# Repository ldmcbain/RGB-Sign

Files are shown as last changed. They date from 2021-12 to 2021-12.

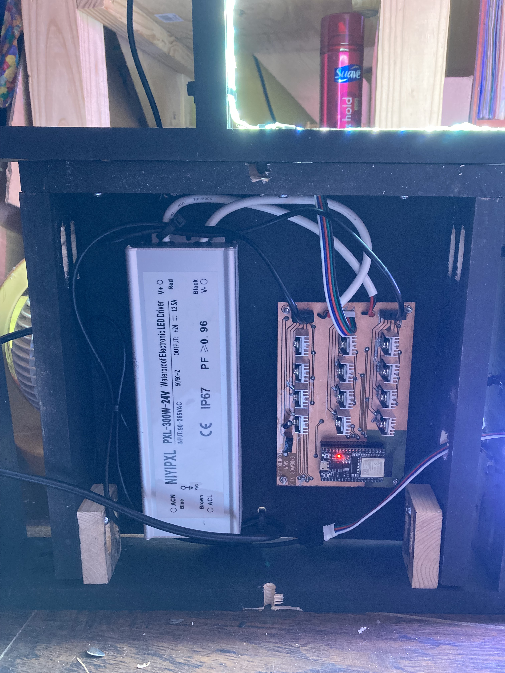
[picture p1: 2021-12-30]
Sign2.jpg

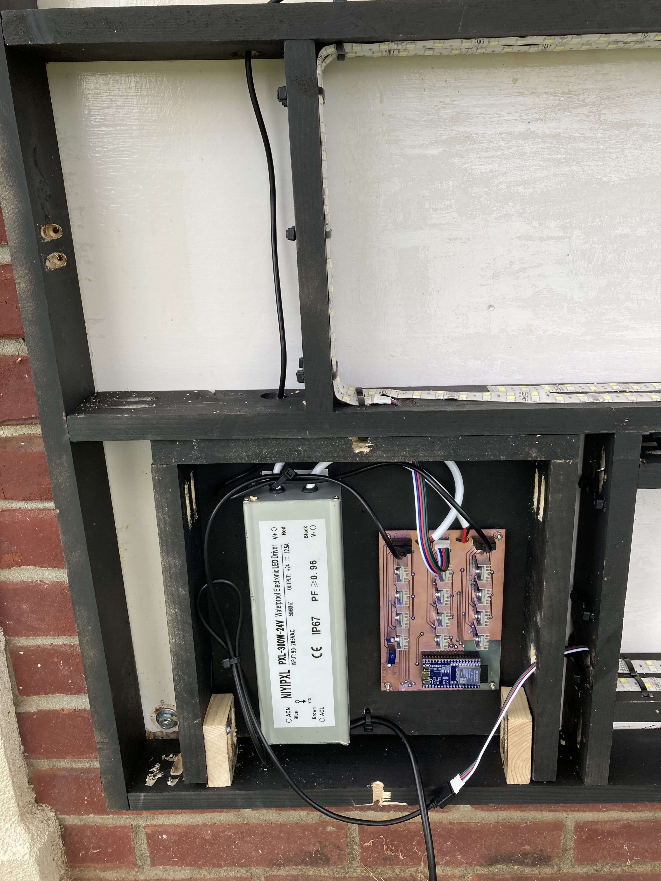
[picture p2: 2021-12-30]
Sign1.jpg

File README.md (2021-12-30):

# RGB Sign
 RGB Wifi Sign Controller using ESP32-DevkitC-32E

This is an RGB Sign I created for our church.  It is an Arduino based design using a custom PCB I created to conrol three separate RGB strings.  I created the PCB using a two-sided copper board and a laser burner, but someone could just as easily send it out for build.

The Arduino is setup to create a WIFI captive portal which is used to control the three strands. Update the wifi settings in the arduino code prior to use.

Note that the PCB uses the ESP32-DevkitC-32E layout.  Other ESP32 variations may have incorrect dimensions or pinouts.

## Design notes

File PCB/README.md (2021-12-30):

This PCB was created in KiCad v5.1.10

I generated the PCB using a standard 5W laser.  Here are my steps to do so if you are so inclined:

Like all things, follow these steps at your own risk.  This process involves toxic chemicals, soldering, etc and you must follow proper safety precautions if attempting.  If you are not comfortable with the equipment/process, don't do it.

**KiCad Design**
  Min Trace Width: 0.4mm
  Min Clearance: 0.25mm
  All Vias should be 2.5mm diameter and not placed under anything
  Use a ground flood plane on most surfaces (reduces required lasering)
  
**From within PCBNew**
  Plot out Top/Bottom Cu layers to PDF.  Utilize small drill holes, show cut edge on all layers
  
**Using GIMP**
1. Import PDF as high res (2400 dpi)
2. Auto Crop to content
3. Modify to fill in the outer edge so that it is all black (don't laser the edges)
4. Export as high res PNG

**Prepare the Board**
1. (optional) Sand the board lightly with 400 grit
2. Spray paint the board (both sides).  Make sure fully coated.  I used the cheap matte black spray at walmart.  Use two coats if needed.

**Lightburn Laser Control SW**
1. Import PNG into lightburn
2. Use Following settings for laser (this is what worked for me, modify as needed)
  a. 60% power
  b. speed: 3mm/s
  c. Bi-directional: Off
  d. Negative Image: On
  e. Overscanning: Off
  f. Line Interval: 0.1mm
  g. Passes: 1

**Burning and Post Clean up/Fabrication**
1. Position and Burn the Board (one side at a time..).  Note: you should be burning a Negative image on the board (areas in-between the copper).
2. Clean up board with scotch bright pad (and water).  Use a ultra fine tip marker to fix damaged areas if needed.
3. After both sides are burned, etch the board using ferric chloride solution.  This can be obtained from amazon.  USE GLOVES!!  There are several youtube videos showing how to do this if you are unfamiliar with the process.
4. Clean the board with water.  Inspect and re-etch if needed.
5. Use acetone or paint thinner to remove remaining paint from the board.
6. Clean board with alcohol (i use the 90% stuff at walmart)
7. Drill the holes.  I obtained very small drills from amazon for the purpose and used a drill press.  Use 0.8mm dia for vias.  They *should* be marked with small dots.  use the drill map to make sure you get all of them with the right size drills.
8. In some instances, I've found it helpful to pre-tin the board in certain locations.
9. Assemble the board.

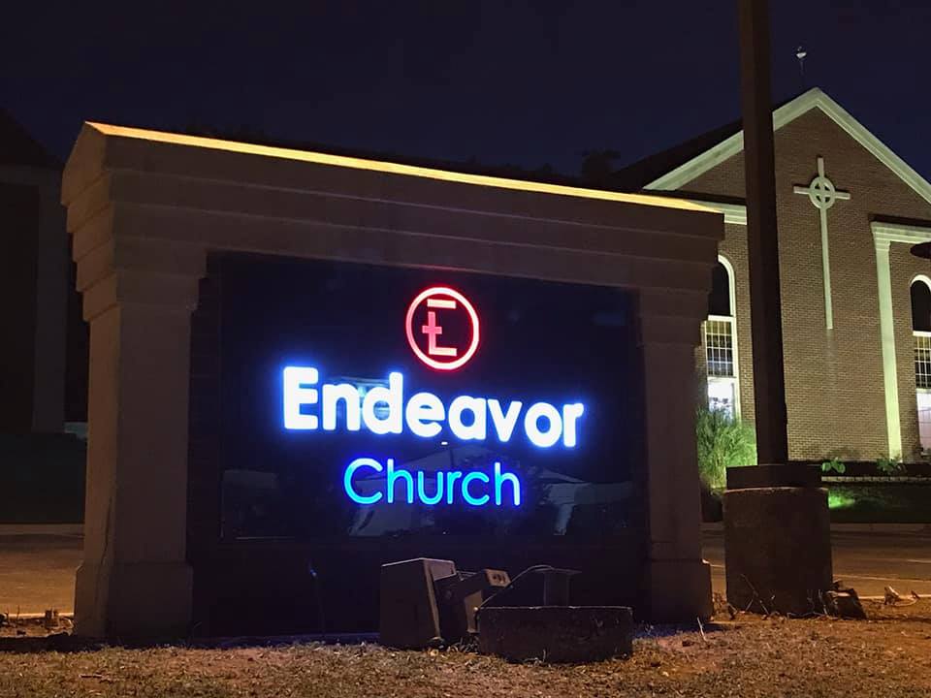
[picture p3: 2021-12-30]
Sign.jpg

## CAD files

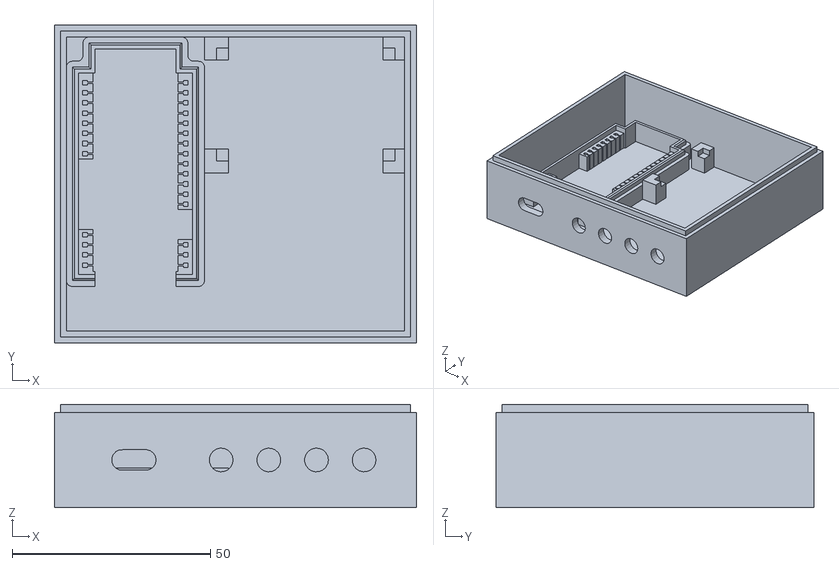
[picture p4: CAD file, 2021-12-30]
Sign/case/Bottom.stl
91.2 x 80.0 x 26.0

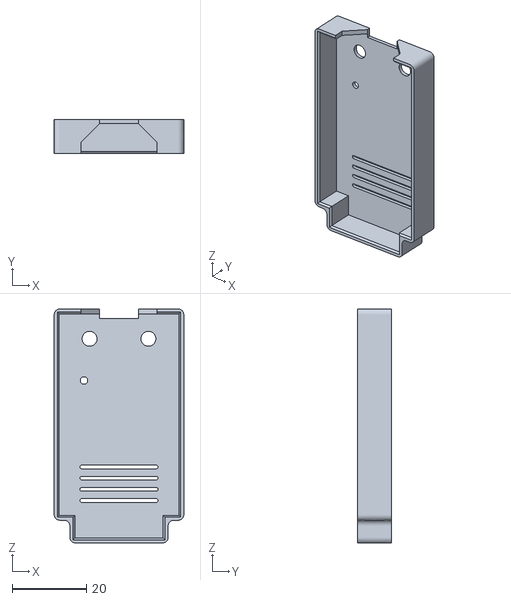
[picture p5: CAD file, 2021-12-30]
Sign/case/TapaESP32-DevKitC.stl
34.8 x 9.00 x 62.8

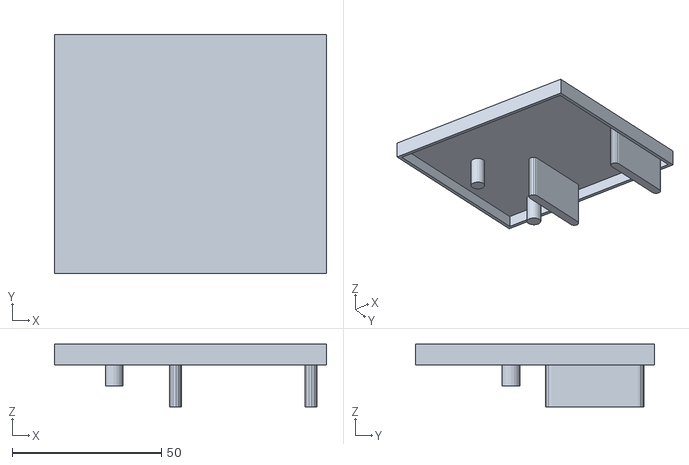
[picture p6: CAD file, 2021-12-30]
Sign/case/Top.stl
91.2 x 80.0 x 21.0

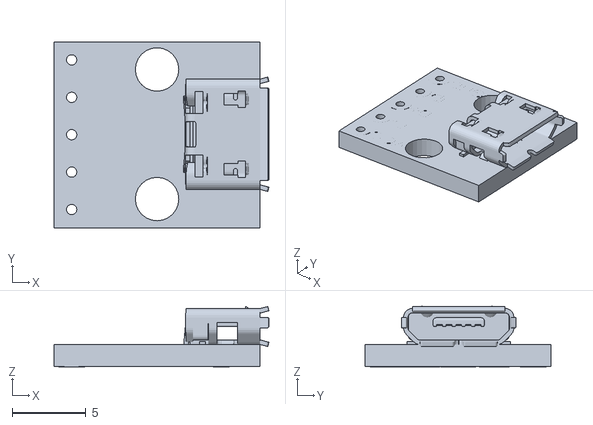
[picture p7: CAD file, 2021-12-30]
Sign/case/USBPinboard.stl
14.6 x 12.6 x 4.11

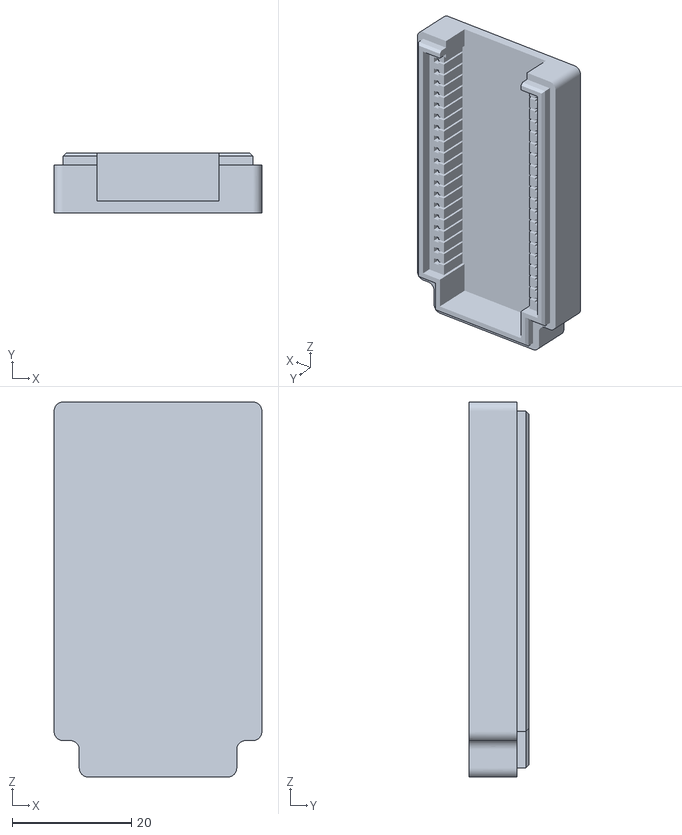
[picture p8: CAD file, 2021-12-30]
Sign/case/CajaESP32-DevKitC.stl
34.8 x 10.0 x 62.8

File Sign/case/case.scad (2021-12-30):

$fs=1;
$fa=3;

boxw=91.2;
boxl=80;
d=3;
boxh=29;

Bottom();
%Top();
pcbsupp();
%models();
BoxBot();
*BoxTop();

module BoxBot(){
  translate([-20.39,-37.3,-2])
difference(){
  cube([boxw,boxl,boxh-3]);
  translate([d,d,2])
  cube([boxw-2*d,boxl-2*d,50]);
  translate([0,0,boxh-5])
  difference(){
    translate([-5,-5,0])
    cube([boxw+10,boxl+10,3]);
    translate([1.5,1.5,-1])
    cube([boxw-3,boxl-3,3]);
  }
  translate([42,0,12])
  rotate([90,0,0])
  for(i=[0:3]){
    translate([12*i,0,0])
  cylinder(r=3,h=10,center=true);
  }
  
  //hole for usb pwr
  translate([17,0,12])
  rotate([90,0,0])
  hull(){
  cylinder(r=2.6,h=10,center=true);
    translate([6,0,0])
  cylinder(r=2.6,h=10,center=true);
  }
}   
}

module BoxTop(){
  translate([-20.39,42.7,boxh])
  rotate([180,0,0])
  union(){
    difference(){
      cube([boxw,boxl,7]);
      translate([d/2,d/2,2])
      cube([boxw-d,boxl-d,50]);
    }   
    
  translate([20,8,0])
  cylinder(r=3,h=14);
    
  translate([20,48,0])
  cylinder(r=3,h=14);
  
  for(i=[0,1]){
    hull(){
  for(j=[0,1]){
  translate([40.5+45.5*i,5.5+29*j,0])
  cylinder(r=2,h=21);
  }
  }}
}
}

module Bottom(){
rotate([90,0,0])
  difference(){
import("CajaESP32-DevKitC.stl",convexity=5);
    translate([-14.40,0,-0.1+2.54/2-2.54*4])
   cube([4,10,2.54*7]);
    translate([10.40,0,-0.1+2.54/2+2.54])
   cube([4,10,2.54*3]);
  }
}


module Top(){
rotate([90,0,0])
import("TapaESP32-DevKitC.stl",convexity=5);
}

module pcbsupp(){
  pcbw=45;
  pcbl=28.5;
  d=3;
  h=6;
translate([20.4-3,8.5-3,0])
difference(){
  translate([0,0,-2])
  cube([pcbw+2*d,pcbl+2*d,h+2+2]);
  translate([d*2,d*2,0])
  cube([pcbw-2*d,pcbl-2*d,12]);
  translate([d,d,h])
  cube([pcbw,pcbl,12]);
  translate([-d,d*2,0])
  cube([pcbw+d*4,pcbl-d*2,12]);
  translate([d*2,-d,0])
  cube([pcbw-d*2,pcbl+d*4,12]);
}
}

module models(){
translate([20.4,8.5,6])
cube([45,28.5,2]);
  
translate([7.5,-10,7])
rotate([0,0,-90])
import("usbpinboard.stl",convexity=5);
  
}

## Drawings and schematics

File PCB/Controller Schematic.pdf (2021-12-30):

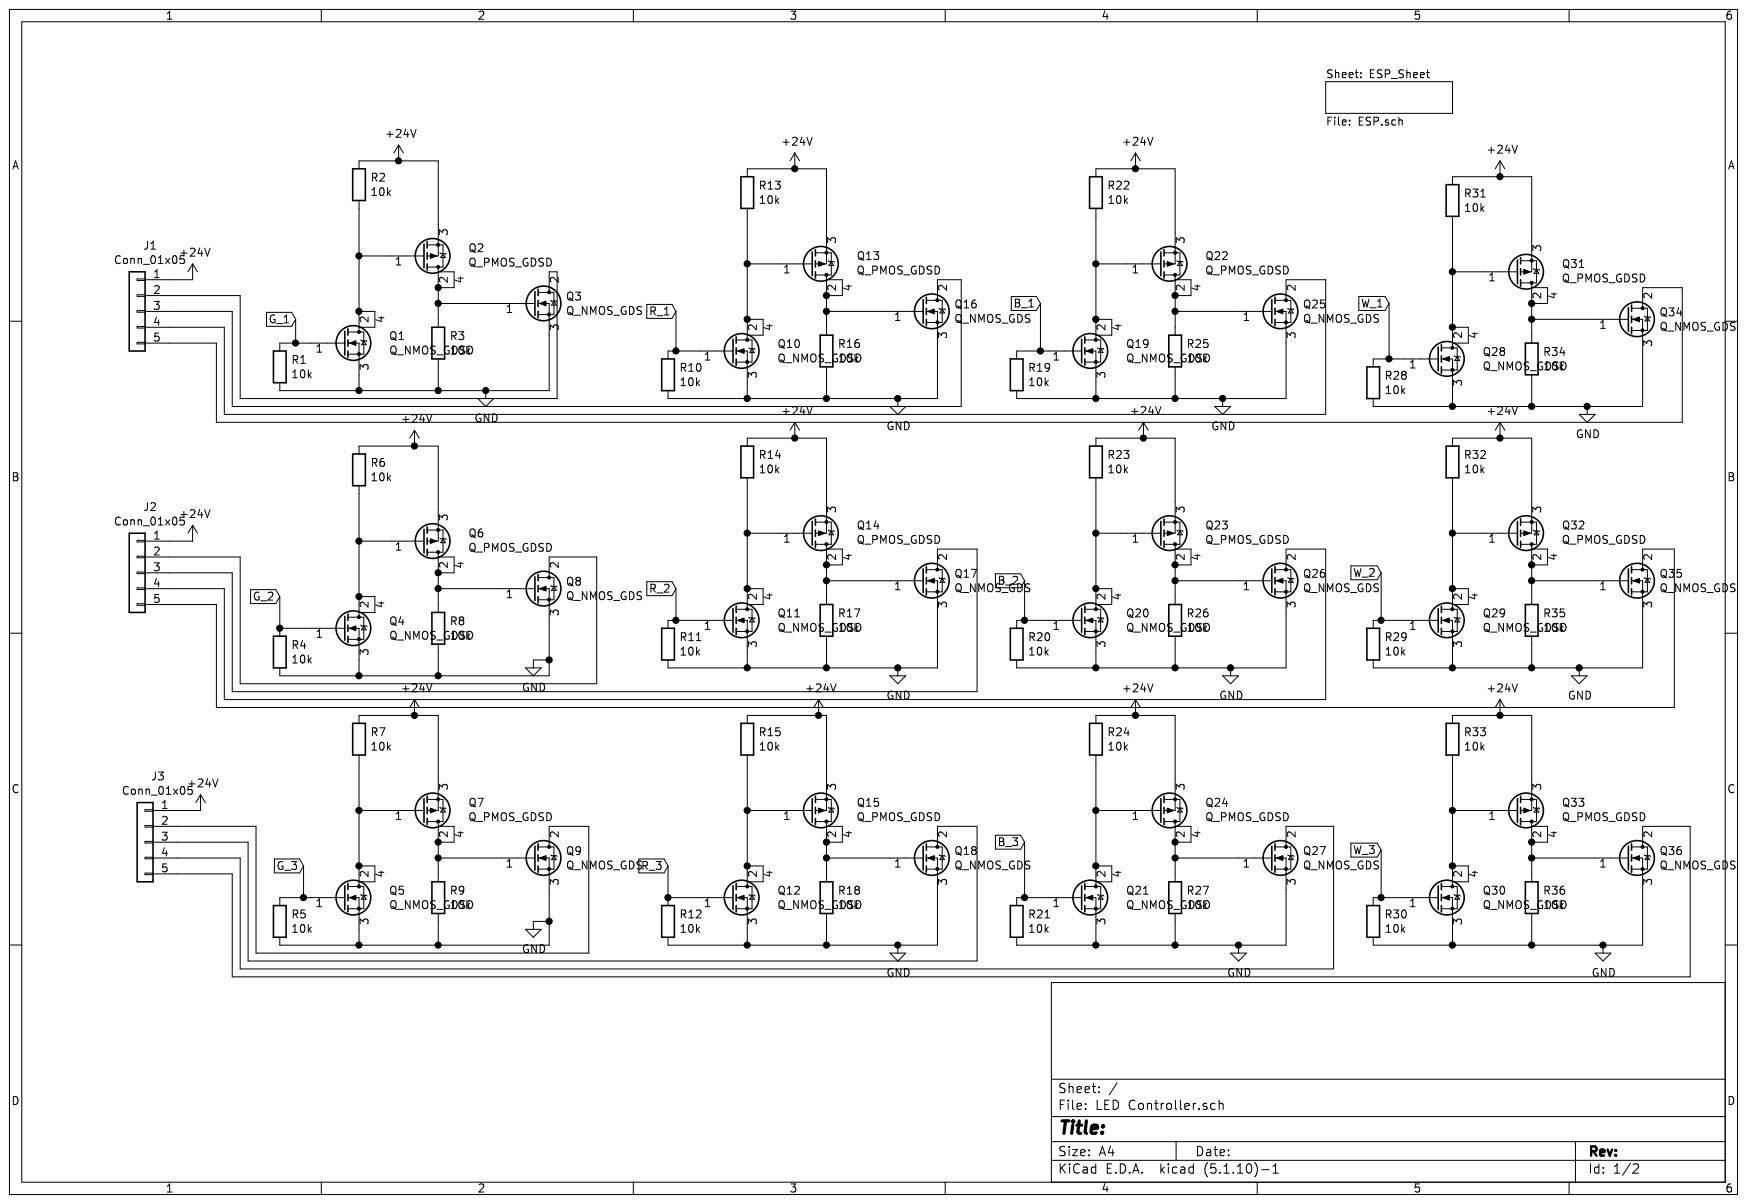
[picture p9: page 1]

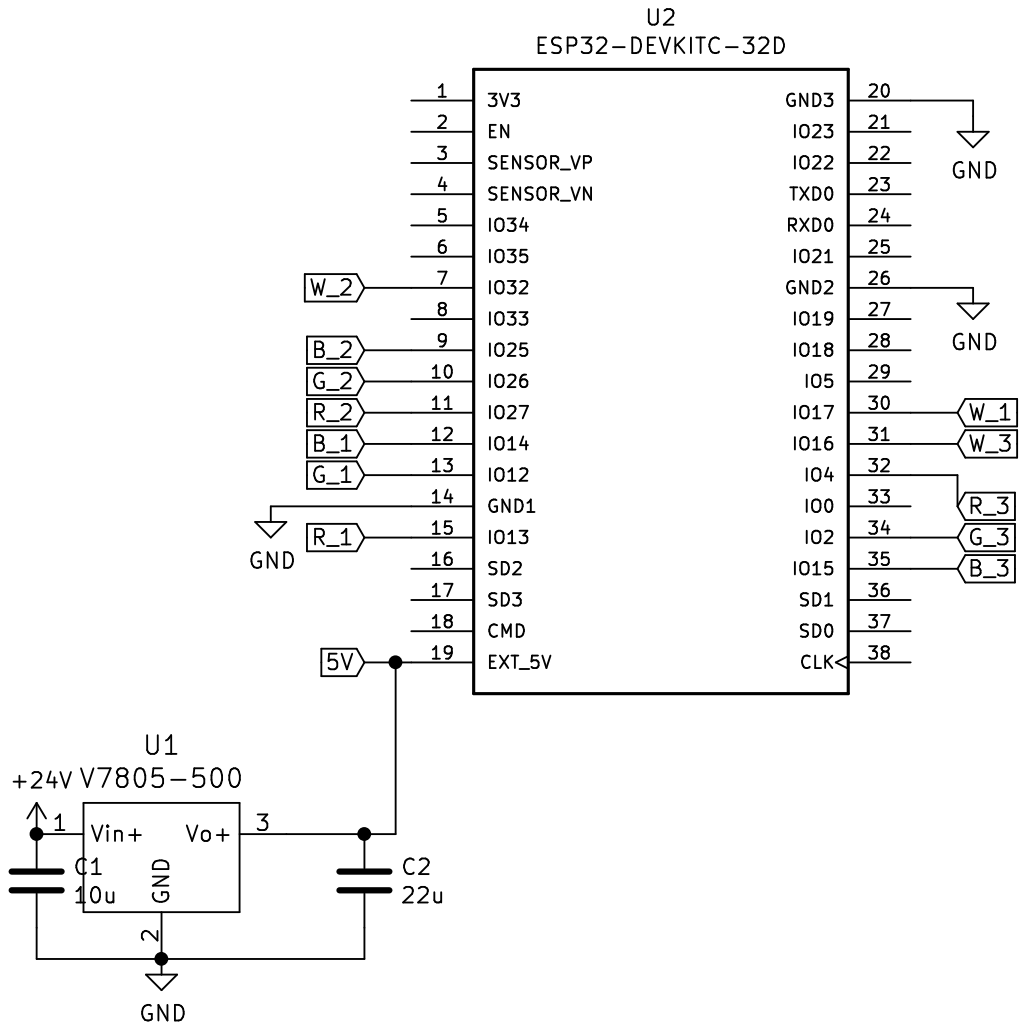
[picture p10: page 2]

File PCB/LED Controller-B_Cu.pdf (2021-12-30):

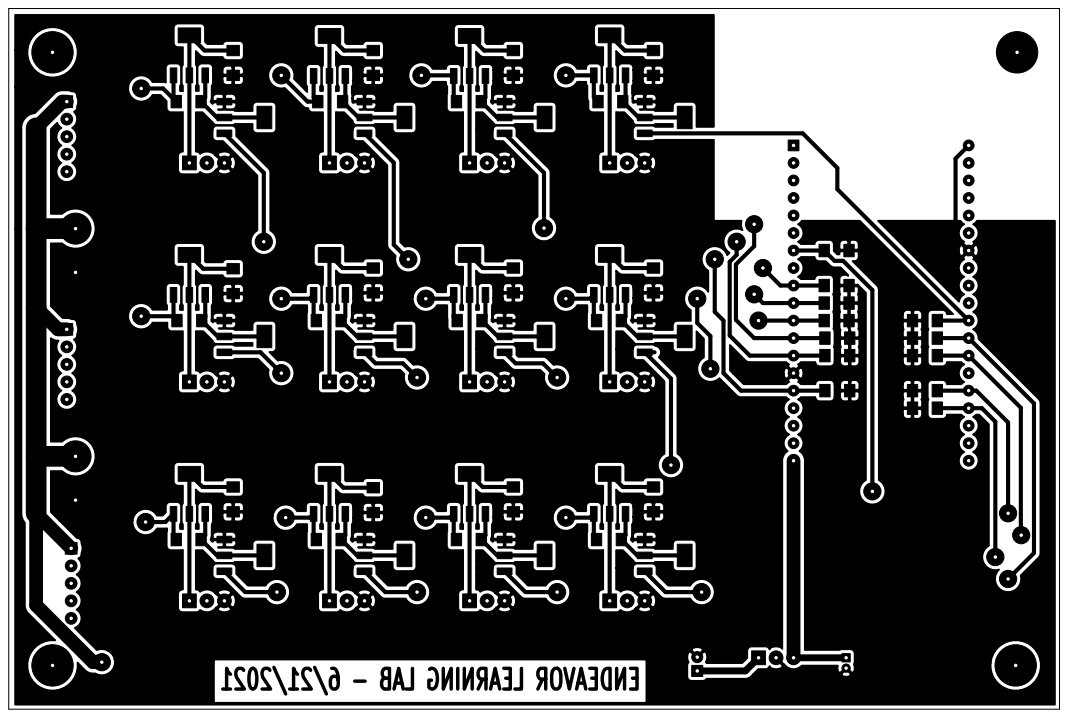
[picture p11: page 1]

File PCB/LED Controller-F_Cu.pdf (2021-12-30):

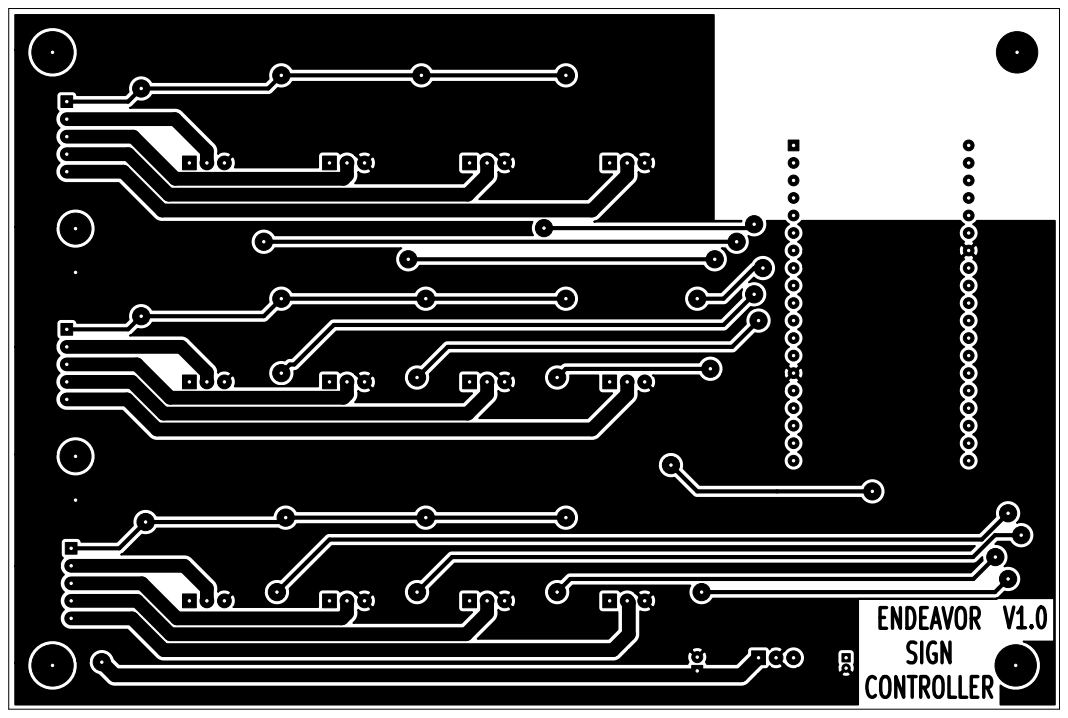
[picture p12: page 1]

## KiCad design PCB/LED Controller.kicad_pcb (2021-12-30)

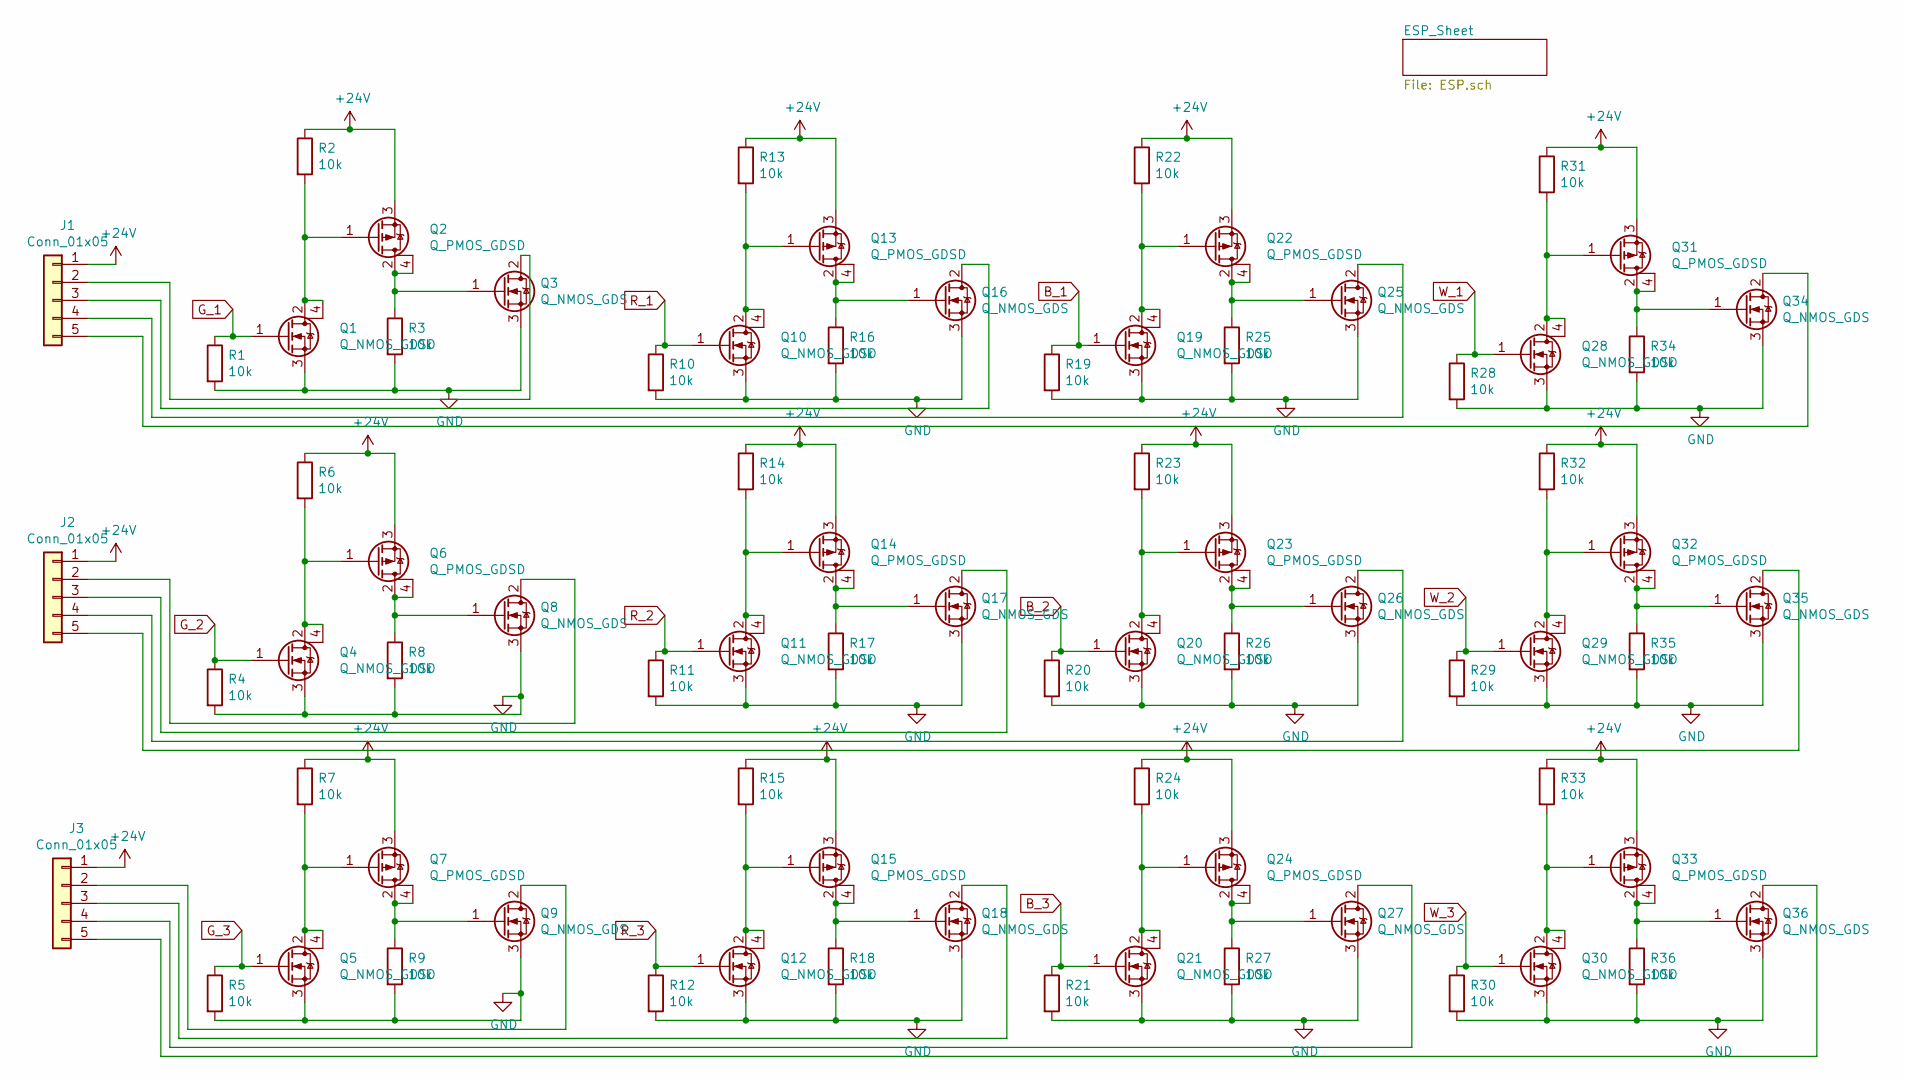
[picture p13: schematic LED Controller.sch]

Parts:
J1, J2, J3: Conn_01x05; PinHeader_1x05_P2.54mm_Vertical
Q1, Q4, Q5, Q10, Q11, Q12, Q19, Q20, Q21, Q28, Q29, Q30: Q_NMOS_GDSD; SOT-223-4
Q2, Q6, Q7, Q13, Q14, Q15, Q22, Q23, Q24, Q31, Q32, Q33: Q_PMOS_GDSD; SOT-223-4
Q3, Q8, Q9, Q16, Q17, Q18, Q25, Q26, Q27, Q34, Q35, Q36: Q_NMOS_GDS; TO-220-3_Heatsink
R1, R2, R3, R4, R5, R6, R7, R8, R9, R10, R11, R12, R13, R14, R15, R16, R17, R18, R19, R20, R21, R22, R23, R24, R25, R26, R27, R28, R29, R30, R31, R32, R33, R34, R35, R36: 10k; 1206

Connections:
+24V: J1.1, J2.1, J3.1, Q2.3 (S), Q6.3 (S), Q7.3 (S), Q13.3 (S), Q14.3 (S), Q15.3 (S), Q22.3 (S), Q23.3 (S), Q24.3 (S), Q31.3 (S), Q32.3 (S), Q33.3 (S), R2.1, R6.1, R7.1, R13.1, R14.1, R15.1, R22.1, R23.1, R24.1, R31.1, R32.1, R33.1; also elsewhere on the board
B_1: Q19.1 (G), R19.1; also elsewhere on the board
B_2: Q20.1 (G), R20.1; also elsewhere on the board
B_3: Q21.1 (G), R21.1; also elsewhere on the board
GND: Q1.3 (S), Q3.3 (S), Q4.3 (S), Q5.3 (S), Q8.3 (S), Q9.3 (S), Q10.3 (S), Q11.3 (S), Q12.3 (S), Q16.3 (S), Q17.3 (S), Q18.3 (S), Q19.3 (S), Q20.3 (S), Q21.3 (S), Q25.3 (S), Q26.3 (S), Q27.3 (S), Q28.3 (S), Q29.3 (S), Q30.3 (S), Q34.3 (S), Q35.3 (S), Q36.3 (S), R1.2, R3.2, R4.2, R5.2, R8.2, R9.2, R10.2, R11.2, R12.2, R16.2, R17.2, R18.2, R19.2, R20.2, R21.2, R25.2, R26.2, R27.2, R28.2, R29.2, R30.2, R34.2, R35.2, R36.2; also elsewhere on the board
G_1: Q1.1 (G), R1.1; also elsewhere on the board
G_2: Q4.1 (G), R4.1; also elsewhere on the board
G_3: Q5.1 (G), R5.1; also elsewhere on the board
unnamed: J1.2, Q3.2 (D)
unnamed: J1.3, Q16.2 (D)
unnamed: J1.4, Q25.2 (D)
unnamed: J1.5, Q34.2 (D)
unnamed: J2.2, Q8.2 (D)
unnamed: J2.3, Q17.2 (D)
unnamed: J2.4, Q26.2 (D)
unnamed: J2.5, Q35.2 (D)
unnamed: J3.2, Q9.2 (D)
unnamed: J3.3, Q18.2 (D)
unnamed: J3.4, Q27.2 (D)
unnamed: J3.5, Q36.2 (D)
unnamed: Q1.2 (D), Q1.4 (D), Q2.1 (G), R2.2
unnamed: Q2.2 (D), Q2.4 (D), Q3.1 (G), R3.1
unnamed: Q4.2 (D), Q4.4 (D), Q6.1 (G), R6.2
unnamed: Q5.2 (D), Q5.4 (D), Q7.1 (G), R7.2
unnamed: Q6.2 (D), Q6.4 (D), Q8.1 (G), R8.1
unnamed: Q7.2 (D), Q7.4 (D), Q9.1 (G), R9.1
unnamed: Q10.2 (D), Q10.4 (D), Q13.1 (G), R13.2
unnamed: Q11.2 (D), Q11.4 (D), Q14.1 (G), R14.2
unnamed: Q12.2 (D), Q12.4 (D), Q15.1 (G), R15.2
unnamed: Q13.2 (D), Q13.4 (D), Q16.1 (G), R16.1
unnamed: Q14.2 (D), Q14.4 (D), Q17.1 (G), R17.1
unnamed: Q15.2 (D), Q15.4 (D), Q18.1 (G), R18.1
unnamed: Q19.2 (D), Q19.4 (D), Q22.1 (G), R22.2
unnamed: Q20.2 (D), Q20.4 (D), Q23.1 (G), R23.2
unnamed: Q21.2 (D), Q21.4 (D), Q24.1 (G), R24.2
unnamed: Q22.2 (D), Q22.4 (D), Q25.1 (G), R25.1
unnamed: Q23.2 (D), Q23.4 (D), Q26.1 (G), R26.1
unnamed: Q24.2 (D), Q24.4 (D), Q27.1 (G), R27.1
unnamed: Q28.2 (D), Q28.4 (D), Q31.1 (G), R31.2
unnamed: Q29.2 (D), Q29.4 (D), Q32.1 (G), R32.2
unnamed: Q30.2 (D), Q30.4 (D), Q33.1 (G), R33.2
unnamed: Q31.2 (D), Q31.4 (D), Q34.1 (G), R34.1
unnamed: Q32.2 (D), Q32.4 (D), Q35.1 (G), R35.1
unnamed: Q33.2 (D), Q33.4 (D), Q36.1 (G), R36.1
R_1: Q10.1 (G), R10.1; also elsewhere on the board
R_2: Q11.1 (G), R11.1; also elsewhere on the board
R_3: Q12.1 (G), R12.1; also elsewhere on the board
W_1: Q28.1 (G), R28.1; also elsewhere on the board
W_2: Q29.1 (G), R29.1; also elsewhere on the board
W_3: Q30.1 (G), R30.1; also elsewhere on the board

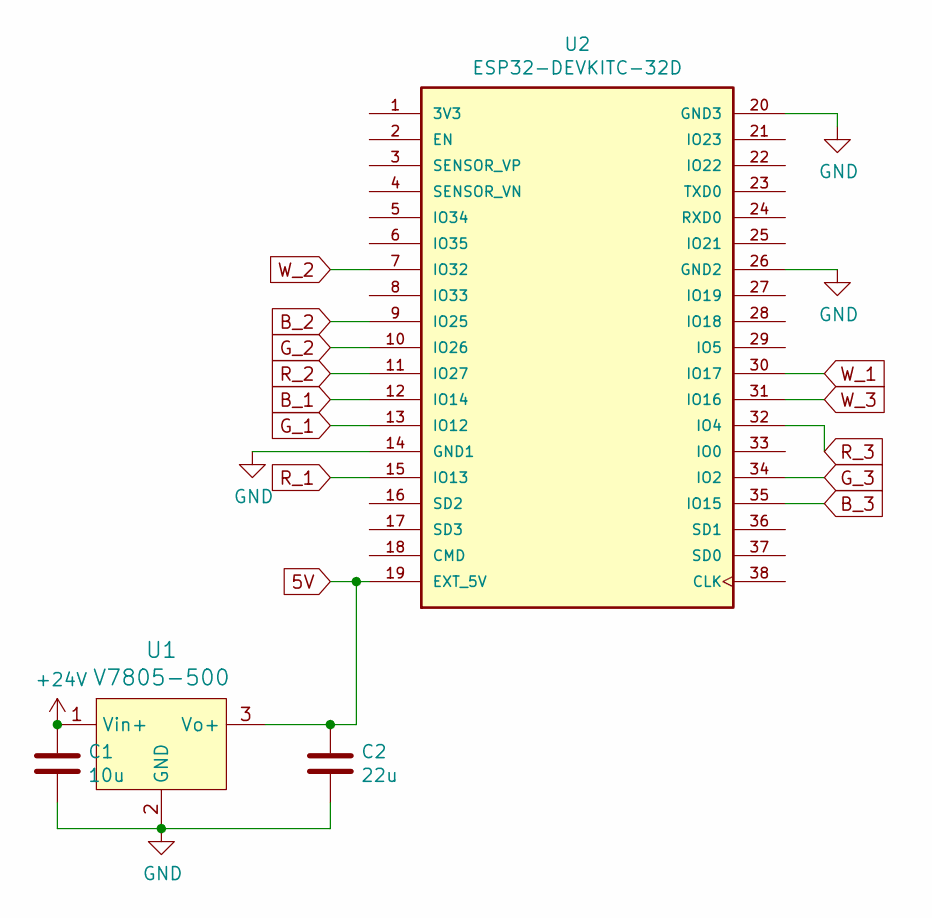
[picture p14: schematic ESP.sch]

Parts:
C1: 10u; CP_Radial_D5.0mm_P2.00mm
C2: 22u; CP_Radial_D4.0mm_P1.50mm
U1: V7805-500; 3-SIP_Module_V7805-500; MPN V7805-500; Digi-Key_PN 102-1709-ND
U2: ESP32-DEVKITC-32D; MODULE_ESP32-DEVKITC-32D; PARTREV 4

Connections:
5V: C2.1, U1.3 (Vo+), U2.19 (EXT_5V)
+24V: C1.1, U1.1 (Vin+); also elsewhere on the board
B_1: U2.12 (IO14); also elsewhere on the board
B_2: U2.9 (IO25); also elsewhere on the board
B_3: U2.35 (IO15); also elsewhere on the board
GND: C1.2, C2.2, U1.2 (GND), U2.14 (GND1), U2.20 (GND3), U2.26 (GND2); also elsewhere on the board
G_1: U2.13 (IO12); also elsewhere on the board
G_2: U2.10 (IO26); also elsewhere on the board
G_3: U2.34 (IO2); also elsewhere on the board
R_1: U2.15 (IO13); also elsewhere on the board
R_2: U2.11 (IO27); also elsewhere on the board
R_3: U2.32 (IO4); also elsewhere on the board
W_1: U2.30 (IO17); also elsewhere on the board
W_2: U2.7 (IO32); also elsewhere on the board
W_3: U2.31 (IO16); also elsewhere on the board

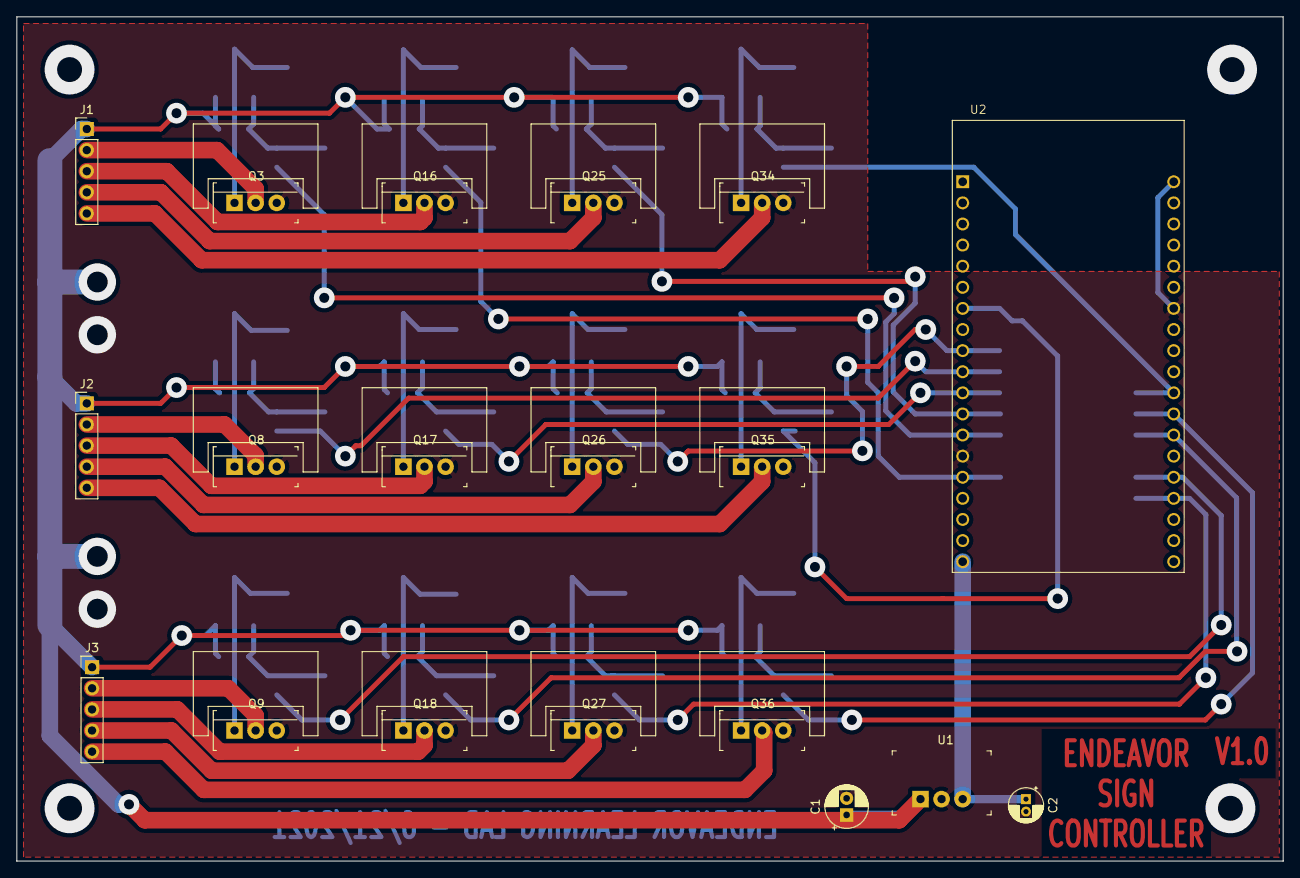
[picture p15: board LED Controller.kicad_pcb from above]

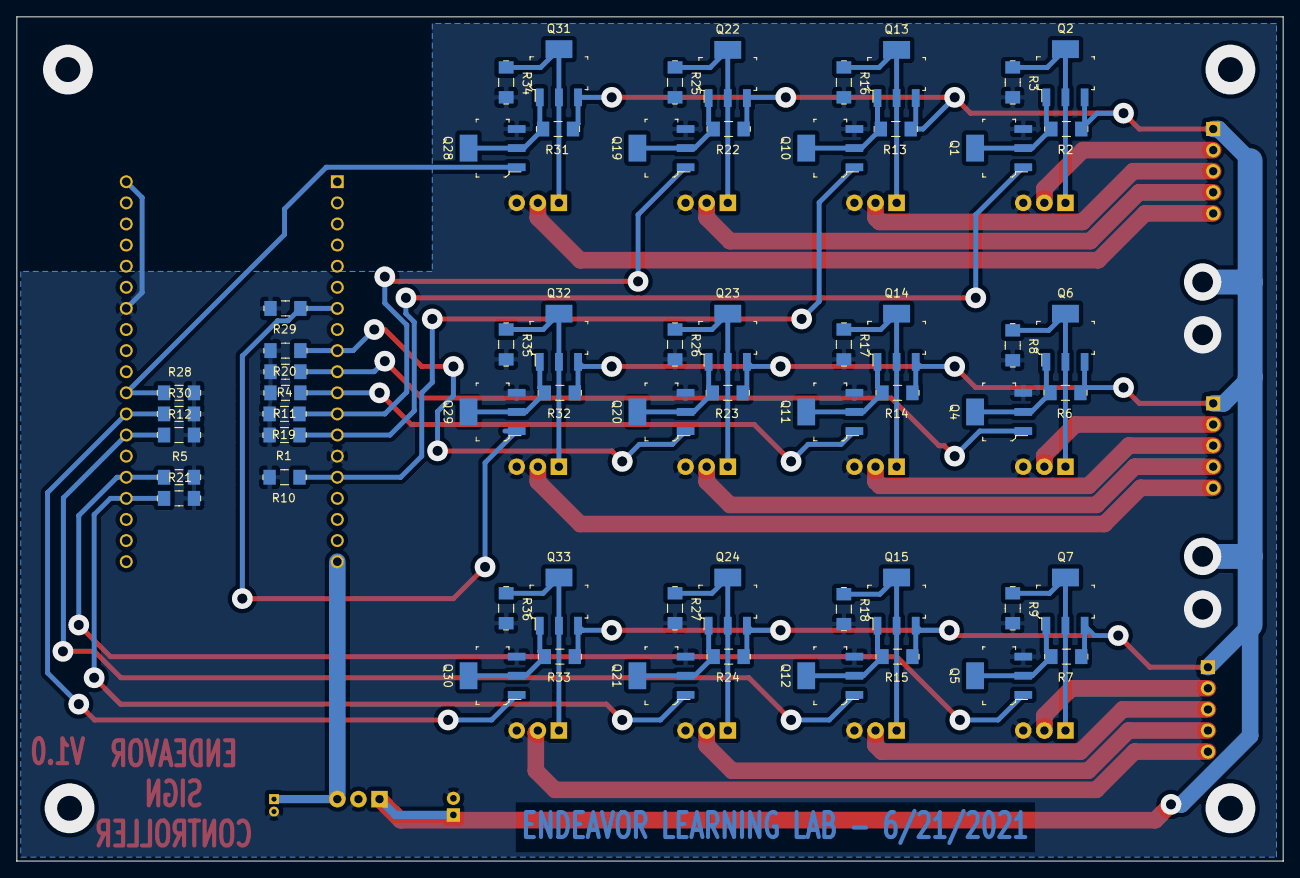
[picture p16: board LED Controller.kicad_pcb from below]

Board: 2 copper layers, 152.4 x 101.6 mm, 79 parts (60 on the bottom side), 51 nets.

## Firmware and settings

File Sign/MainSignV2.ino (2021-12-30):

/*
 * ENDEAVOR LED SIGN CONTROL
 * This project was created by Endeavor Labs (a mission of Endeavor Church) to create
 * an LED controller for the main front sign.  
 * 
 * The system is to be designed to use a ESP32 Dev board to control 3 separate
 * RGBW 5050 LED strips.  The LEDs will be driven via NMOS FETs on the attached 
 * PCB.
 * 
 * This software is designed to create a permanent Access Point with a captive portal
 * to a webpage which will control the three strings using the jscolor color picker 
 * (jscolor.js stored in SPIFFS). The device will then present the user with the
 * ability to save the settings to EEPROM so that the unit will restore settings
 * upon reboot (which will occurr nightly).
 * 
 * This is version 2 which added the white LEDs and also is being used with
 * the incorporated PCB attached to the project.
 * 
 * Board - ESP32 Dev Module
 * Upload Speed - 115200
 * CPU Freq - 240MHz
 * Flash Freq 40MHz
 * Mode - QIO
 * Flash size - 4MB (32Mb)
 * Partition - Default 4MB wigh SPIFFS (1.2MB APP/1.5MB SPIFFS)
 */

#include <Arduino.h>
#include <WebServer.h>
#include <DNSServer.h>
#include "./server_html.h"
#include "./myeeprom.h"
#include <SPIFFS.h>

#define FILESYSTEM SPIFFS

// Replace with your network credentials
const char* ssid     = "XXXXXXXX";
const char* password = "XXXXXXXX";

// Set web server port number to 80
WebServer server(80);
const byte DNS_PORT = 53;
IPAddress apIP(192, 168, 1, 1);
DNSServer dnsServer;

// Red, green, and blue pins for PWM control
const int redPin[MAX_leds] = {13,27,4};     // 13 corresponds to GPIO13
const int greenPin[MAX_leds] = {12,26,2};   // 12 corresponds to GPIO12
const int bluePin[MAX_leds] = {14,25,15};    // 14 corresponds to GPIO14
const int whitePin[MAX_leds] = {17,32,16};    // 14 corresponds to GPIO14

// Setting PWM frequency, channels and bit resolution
//resolution set down to 300 to improve resolution in low/high settings.
const int freq = 300;
const int redChannel[MAX_leds] = {0,1,2};
const int greenChannel[MAX_leds] = {3,4,5};
const int blueChannel[MAX_leds] = {6,7,8};
const int whiteChannel[MAX_leds] = {9,10,11};
// Bit resolution 2^8 = 256
const int resolution = 8;

int redInt[3] = {0,0,0};
int blueInt[3] = {0,0,0};
int greenInt[3] = {0,0,0};
int whiteInt[3] = {0,0,0};

void handleRoot()
{
  buildWebsite();
  server.send(200, "text/html", webSite);
}

void handleLED1()
{
  handleLED(0,server.arg("r"),server.arg("g"),server.arg("b"));
}

void handleLED2()
{
  handleLED(1,server.arg("r"),server.arg("g"),server.arg("b"));
}

void handleLED3()
{
  handleLED(2,server.arg("r"),server.arg("g"),server.arg("b"));
}

void handleWHITE1()
{
  handleWHITE(0,server.arg("w"));
}

void handleWHITE2()
{
  handleWHITE(1,server.arg("w"));
}

void handleWHITE3()
{
  handleWHITE(2,server.arg("w"));
}

void handleSAVE()
{
  Serial.println("Saving Settings");
  int i;
  for(i=0;i<MAX_leds;i++)
  {
    Serial.printf("R%i:%s G%i:%s B%i:%s W%i:%s ",i,redString[i].c_str(),i,greenString[i].c_str(),i,blueString[i].c_str(),i,whiteString[i].c_str());
  }
  Serial.println("");
  saveSettings(redString[0],greenString[0],blueString[0],whiteString[0],
               redString[1],greenString[1],blueString[1],whiteString[1],
               redString[2],greenString[2],blueString[2],whiteString[2]);
}

void handleRESTORE()
{
  getStoredSettings();
  redString[0]=String(romSettings.RD1);
  greenString[0]=String(romSettings.GR1);
  blueString[0]=String(romSettings.BL1);
  whiteString[0]=String(romSettings.WH1);
  redString[1]=String(romSettings.RD2);
  greenString[1]=String(romSettings.GR2);
  blueString[1]=String(romSettings.BL2);
  whiteString[1]=String(romSettings.WH2);
  redString[2]=String(romSettings.RD3);
  greenString[2]=String(romSettings.GR3);
  blueString[2]=String(romSettings.BL3);
  whiteString[2]=String(romSettings.WH3);

  
  Serial.println("Restore String Settings");
  int i;
  for(i=0;i<MAX_leds;i++)
  {
    Serial.printf("R%i:%s G%i:%s B%i:%s W%i:%s ",i,redString[i].c_str(),i,greenString[i].c_str(),i,blueString[i].c_str(),i,whiteString[i].c_str());
  }
  Serial.println("");
  
  for(i=0;i<MAX_leds;i++)
  {
    handleLED(i,redString[i],greenString[i],blueString[i]);
    handleWHITE(i,whiteString[i]);
  }
}

void handleLED(int LED, String r, String g, String b)
{  
  redString[LED] = r;
  greenString[LED] = g;
  blueString[LED] = b;
  
  ledcWrite(redChannel[LED], r.toInt());
  ledcWrite(greenChannel[LED], g.toInt());
  ledcWrite(blueChannel[LED], b.toInt());
  
  Serial.print("LED");
  Serial.print(LED);
  Serial.print(" Set to: RED:");
  Serial.print(r);
  Serial.print(" GREEN:");
  Serial.print(g);
  Serial.print(" BLUE:");
  Serial.println(b);
}

void handleWHITE(int LED, String w)
{
  whiteString[LED] = w;
  ledcWrite(whiteChannel[LED], w.toInt());
  
  Serial.print("LED");
  Serial.print(LED);
  Serial.print(" Set to: WHITE:");
  Serial.println(w);
}

void setup() {
  Serial.begin(115200);
  int i;
  for(i=0;i<MAX_leds;i++)
  {
    // configure LED PWM functionalitites
    ledcSetup(redChannel[i], freq, resolution);
    ledcSetup(greenChannel[i], freq, resolution);
    ledcSetup(blueChannel[i], freq, resolution);
    ledcSetup(whiteChannel[i], freq, resolution);
    
    // attach the channel to the GPIO to be controlled
    ledcAttachPin(redPin[i], redChannel[i]);
    ledcAttachPin(greenPin[i], greenChannel[i]);
    ledcAttachPin(bluePin[i], blueChannel[i]);
    ledcAttachPin(whitePin[i], whiteChannel[i]);
  }

  // Initialize SPIFFS
  if(!FILESYSTEM.begin(true)){
    Serial.println("An Error has occurred while mounting SPIFFS");
    return;
  }

  //restore settings from EEPROM
  handleRESTORE();
  
  // Connect to Wi-Fi network with SSID and password
  Serial.print("Starting AP ");
  Serial.println(ssid);

  WiFi.mode(WIFI_AP);
  Serial.println(WiFi.softAP(ssid, password) ? "soft-AP setup": "Failed to connect");
  delay(100);
  Serial.println(WiFi.softAPConfig(apIP, apIP, IPAddress(255, 255, 255, 0))? "Configuring Soft AP" : "Error in Configuration");


  //setup captive portal so all traffic goes to main page
  dnsServer.start(DNS_PORT, "*", apIP);
  
  Serial.println("");
  Serial.println("WiFi connected.");
  Serial.print("IP:");
  Serial.println(WiFi.softAPIP());
  startWebServer();
}

void loop(){
  dnsServer.processNextRequest();
  server.handleClient();
}

void startWebServer()
{  
  server.on("/jscolor.js", HTTP_GET, [](){
    if (!handleFileRead("/jscolor.js")) {
      server.send(404, "text/plain", "FileNotFound");
    }
  });
  server.on( "/", handleRoot);
  server.on("/setLED1",handleLED1);
  server.on("/setLED2",handleLED2);
  server.on("/setLED3",handleLED3);
  server.on("/setWHITE1",handleWHITE1);
  server.on("/setWHITE2",handleWHITE2);
  server.on("/setWHITE3",handleWHITE3);
  server.on("/SAVE",handleSAVE);
  server.on("/RESTORE",handleRESTORE);
  server.onNotFound(handleRoot);
  server.begin();
}

bool handleFileRead(String path) {
  String contentType = getContentType(path);
  if (exists(path)) {
    File file = FILESYSTEM.open(path, "r");
    server.streamFile(file, contentType);
    file.close();
    return true;
  }
  return false;
}

String getContentType(String filename) {
  if (server.hasArg("download")) {
    return "application/octet-stream";
  } else if (filename.endsWith(".htm")) {
    return "text/html";
  } else if (filename.endsWith(".html")) {
    return "text/html";
  } else if (filename.endsWith(".css")) {
    return "text/css";
  } else if (filename.endsWith(".js")) {
    return "application/javascript";
  } else if (filename.endsWith(".png")) {
    return "image/png";
  } else if (filename.endsWith(".gif")) {
    return "image/gif";
  } else if (filename.endsWith(".jpg")) {
    return "image/jpeg";
  } else if (filename.endsWith(".ico")) {
    return "image/x-icon";
  } else if (filename.endsWith(".xml")) {
    return "text/xml";
  } else if (filename.endsWith(".pdf")) {
    return "application/x-pdf";
  } else if (filename.endsWith(".zip")) {
    return "application/x-zip";
  } else if (filename.endsWith(".gz")) {
    return "application/x-gzip";
  }
  return "text/plain";
}

bool exists(String path){
  bool yes = false;
  File file = FILESYSTEM.open(path, "r");
  if(!file.isDirectory()){
    yes = true;
  }
  file.close();
  return yes;
}

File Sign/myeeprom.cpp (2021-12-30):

#include "./myeeprom.h"


StoredSettings romSettings;



/**
 * Retrieves stored settings from EEPROM so that WiFi setup does not have to be repeated on every power cycle
 * 
 * @return struct
 * @author costmo
 * @since  20180929
 */
StoredSettings getStoredSettings()
{
  uint addr = 0;
  EEPROM.begin( 512 );
  EEPROM.get( addr, romSettings );
  EEPROM.end();
  itoa(constrain(atoi(romSettings.RD1),0,255),romSettings.RD1,10);
  itoa(constrain(atoi(romSettings.GR1),0,255),romSettings.GR1,10);
  itoa(constrain(atoi(romSettings.BL1),0,255),romSettings.BL1,10);
  itoa(constrain(atoi(romSettings.WH1),0,255),romSettings.WH1,10);
  itoa(constrain(atoi(romSettings.RD2),0,255),romSettings.RD2,10);
  itoa(constrain(atoi(romSettings.GR2),0,255),romSettings.GR2,10);
  itoa(constrain(atoi(romSettings.BL2),0,255),romSettings.BL2,10);
  itoa(constrain(atoi(romSettings.WH2),0,255),romSettings.WH2,10);
  itoa(constrain(atoi(romSettings.RD3),0,255),romSettings.RD3,10);
  itoa(constrain(atoi(romSettings.GR3),0,255),romSettings.GR3,10);
  itoa(constrain(atoi(romSettings.BL3),0,255),romSettings.BL3,10);
  itoa(constrain(atoi(romSettings.WH3),0,255),romSettings.WH3,10);
  /*
  Serial.println("EEPROM c_str RESTORE values:");
  Serial.printf("R1:%s G1:%s B1:%s W1:%s ",romSettings.RD1,romSettings.GR1,romSettings.BL1,romSettings.WH1);
  Serial.printf("R2:%s G2:%s B2:%s W2:%s ",romSettings.RD2,romSettings.GR2,romSettings.BL2,romSettings.WH2);
  Serial.printf("R3:%s G3:%s B3:%s W3:%s ",romSettings.RD3,romSettings.GR3,romSettings.BL3,romSettings.WH3);
  Serial.println("");
  */
  return romSettings;
}


/**
 * Stores the input settings to EEPROM
 * 
 * @return void
 * @author costmo
 * @since  20180929
 */
void saveSettings(String r1, String g1, String b1, String w1, String r2, String g2, String b2, String w2, String r3, String g3, String b3, String w3)
{
  uint addr = 0;

  strcpy( romSettings.RD1, r1.c_str() );
  strcpy( romSettings.GR1, g1.c_str() );
  strcpy( romSettings.BL1, b1.c_str() );
  strcpy( romSettings.WH1, w1.c_str() );
  strcpy( romSettings.RD2, r2.c_str() );
  strcpy( romSettings.GR2, g2.c_str() );
  strcpy( romSettings.BL2, b2.c_str() );
  strcpy( romSettings.WH2, w2.c_str() );
  strcpy( romSettings.RD3, r3.c_str() );
  strcpy( romSettings.GR3, g3.c_str() );
  strcpy( romSettings.BL3, b3.c_str() );
  strcpy( romSettings.WH3, w3.c_str() );
/*
  Serial.println("EEPROM c_str values:");
  Serial.printf("R1:%s G1:%s B1:%s W1:%s ",romSettings.RD1,romSettings.GR1,romSettings.BL1,romSettings.WH1);
  Serial.printf("R2:%s G2:%s B2:%s W2:%s ",romSettings.RD2,romSettings.GR2,romSettings.BL2,romSettings.WH2);
  Serial.printf("R3:%s G3:%s B3:%s W3:%s ",romSettings.RD3,romSettings.GR3,romSettings.BL3,romSettings.WH3);
  Serial.println("");
*/
  EEPROM.begin( 512 );
  EEPROM.put( addr, romSettings );
  EEPROM.end();
}
